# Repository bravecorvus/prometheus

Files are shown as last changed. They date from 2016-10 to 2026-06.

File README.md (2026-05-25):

# Prometheus Smart Clock

### By Andrew Lee

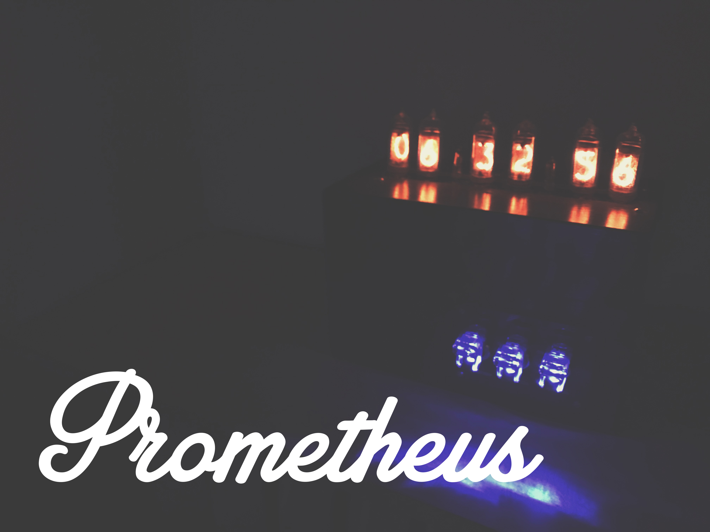
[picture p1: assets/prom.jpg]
Prometheus Clock Cover


Prometheus is the clock that does everything. The 3 main things I want to integrate in this project are:

1. Connect the clock to a bed shaker so my alarm clock can wake me up discretely without waking up my roommate, but also retain the ability to wake me up in a super noisy fashion by playing an alarm tone through my speaker system for when I really need to wake up.
2. A way to set the alarm via my phone, iPad, or Browser through a polished and intuitive web based interface as well as an easy way to set a new alarm sound.
3. Display time using nixie tube displays.

The current golang program accomplishes all 3 of these things marvelously. Check out the [Wiki](https://github.com/gilgameshskytrooper/prometheus/wiki) for specific details on how to implement Prometheus.

### Project Hierarchy

| Directory | Description |
| --- | --- |
| [backend/](backend/) | Go HTTP server, alarm cron loops, bbolt store, GPIO + serial drivers |
| [frontend/](frontend/) | React + Vite + Tailwind + shadcn UI |
| [assets/](assets/) | Project documentation images (READMEs, schematics) |
| [archive/](archive/) | Original Python3/Node prototype (deprecated, kept for reference) |
| [NCS314/](NCS314/) | Vendor docs for the Nixie clock shield |
| [prometheus.service](prometheus.service) | systemd unit; assumes deploy layout under `/home/pi/prometheus/` |

## Build modes

Prometheus has two build modes selected with Go build tags:

- **Production** (default) — full hardware: GPIO bed-shaker control, USB-serial Nixie tube display, `cvlc` audio playback, IP-change email notifications.
- **Demo** (`-tags demo`) — for hosting a public-facing UI showcase. All GPIO and serial code paths are bypassed at compile time; alarm triggers broadcast WebSocket events instead, and the frontend renders a toast (e.g. "Vibration started") to emulate hardware. No `cvlc` or `/dev/gpiomem` required.

`backend/config/config.go` and `config_demo.go` define `config.DemoMode` as a compile-time constant, so unused branches are dead-code-eliminated.

### Build the backend

```bash
cd backend

# Production binary for the Pi (arm64)
GOOS=linux GOARCH=arm64 go build -o ../prometheus .

# Demo binary for arm64
GOOS=linux GOARCH=arm64 go build -tags demo -o ../prometheus-demo .

# Native (macOS / dev)
go build -o ../prometheus .
```

### Build the frontend

```bash
cd frontend
pnpm install
pnpm build       # outputs ./dist
```

### Local development

Run the backend on :3000 and the Vite dev server on :5173 (Vite proxies `/api`, `/audio`, and `/ws` over to the backend):

```bash
# terminal A — backend (dev demo mode is convenient on a laptop)
cd backend && go run -tags demo .

# terminal B — frontend with hot reload
cd frontend && pnpm dev
```

Then open http://localhost:5173.

### Deploy to a Raspberry Pi

The Pi mirrors the repo layout. After a `git clone` of the repo into `/home/pi/prometheus/`, the source-controlled files (service unit, email helper binary, etc.) are already in place; deploying an update just means scp'ing the two build artifacts on top of the clone:

```
/home/pi/prometheus/
├── backend/
│   ├── prometheus              # the cross-compiled Go binary  (scp'd)
│   └── email/prometheusemail   # email helper (already in git)
├── frontend/
│   └── dist/                   # built UI                       (scp'd)
├── data/                       # bbolt DB + uploaded audio (created at first run)
└── prometheus.service          # systemd unit (already in git)
```

From your dev machine:

```bash
# build both artifacts
(cd backend  && GOOS=linux GOARCH=arm64 go build -o ../prometheus .)
(cd frontend && pnpm install && pnpm build)

# scp them into the repo layout on the Pi
scp prometheus       pi@prometheus.local:/home/pi/prometheus/backend/prometheus
scp -r frontend/dist pi@prometheus.local:/home/pi/prometheus/frontend/
```

First-time install on the Pi:

```bash
sudo cp /home/pi/prometheus/prometheus.service /etc/systemd/system/
sudo systemctl daemon-reload
sudo systemctl enable --now prometheus
journalctl -u prometheus -f
```

Subsequent updates:

```bash
sudo systemctl restart prometheus
```

## Implementation
> *To get started quickly, check out the [hardware guide](https://github.com/gilgameshskytrooper/prometheus/wiki/Hardware) and the [software installation guide](https://github.com/gilgameshskytrooper/prometheus/wiki/Software) at the project wiki.*

### Inspiration
hberg32 has already successfully implemented some of the code as well as the hard wiring for a similar project of his. His original code as well as his original schematic is contained in the [hberg32](hberg32/) directory of this repo. His project can be found at: [Merciless Pi Alarm Clock](https://hackaday.io/project/4922-merciless-pi-alarm-clock).

### Hardware

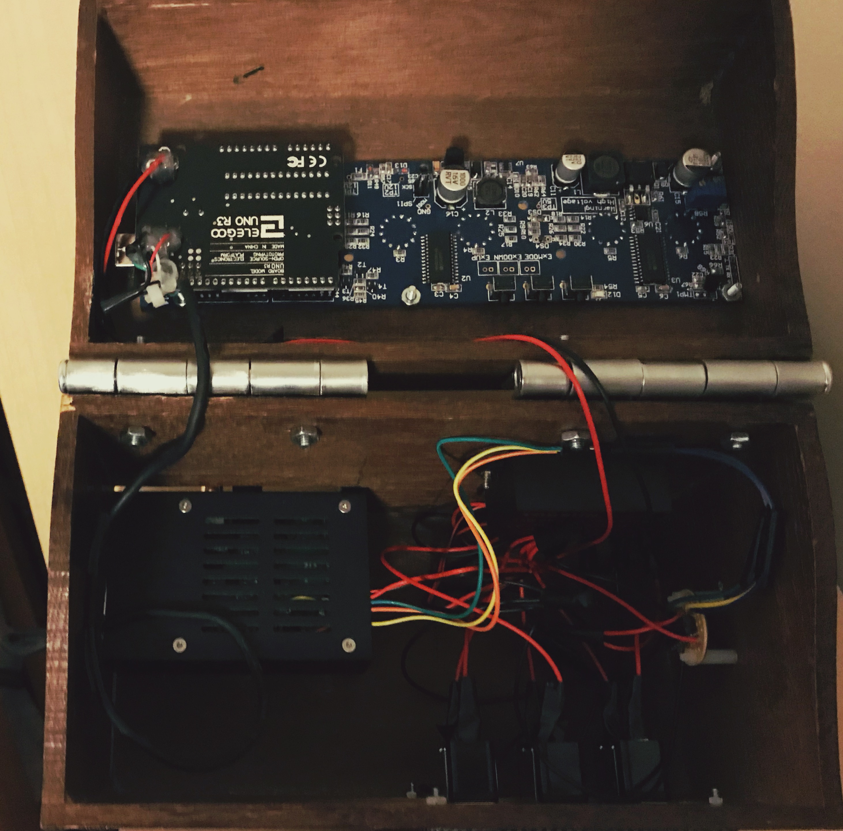
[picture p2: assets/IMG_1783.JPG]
Custom Wire


The hardware in this project is heavily based on hberg32's schematics, which can be found at [Merciless Pi Alarm Schematic](hberg32/PiAlarm.fzz). The schematics of my project can be found at [Prometheus Clock Schematic](/assets/AtomicClockSchematic.fzz).

A few notes on my set-up. My Raspberry Pi has a separate (standard 5V) power source separate from the rest of the Prometheus Clock. The rest of my Project is powered by a 12V @ 2000mA DC Power source, which powers both the Nixie Clock and the Bed Shaker.

As of now, the DC power goes though the breadoard, and goes to both the Nixie Clock, (via a custom barrel plug to breadboard wire I made) as well as a L293D which draws a consistant amount from the main circuit to ensure the clock receives enough V's and the Bed Shaker doesn't fry from too much.

You can read more [here](https://github.com/gilgameshskytrooper/Prometheus/wiki/Hardware-Set-Up)

### Remote Control Alarm Program

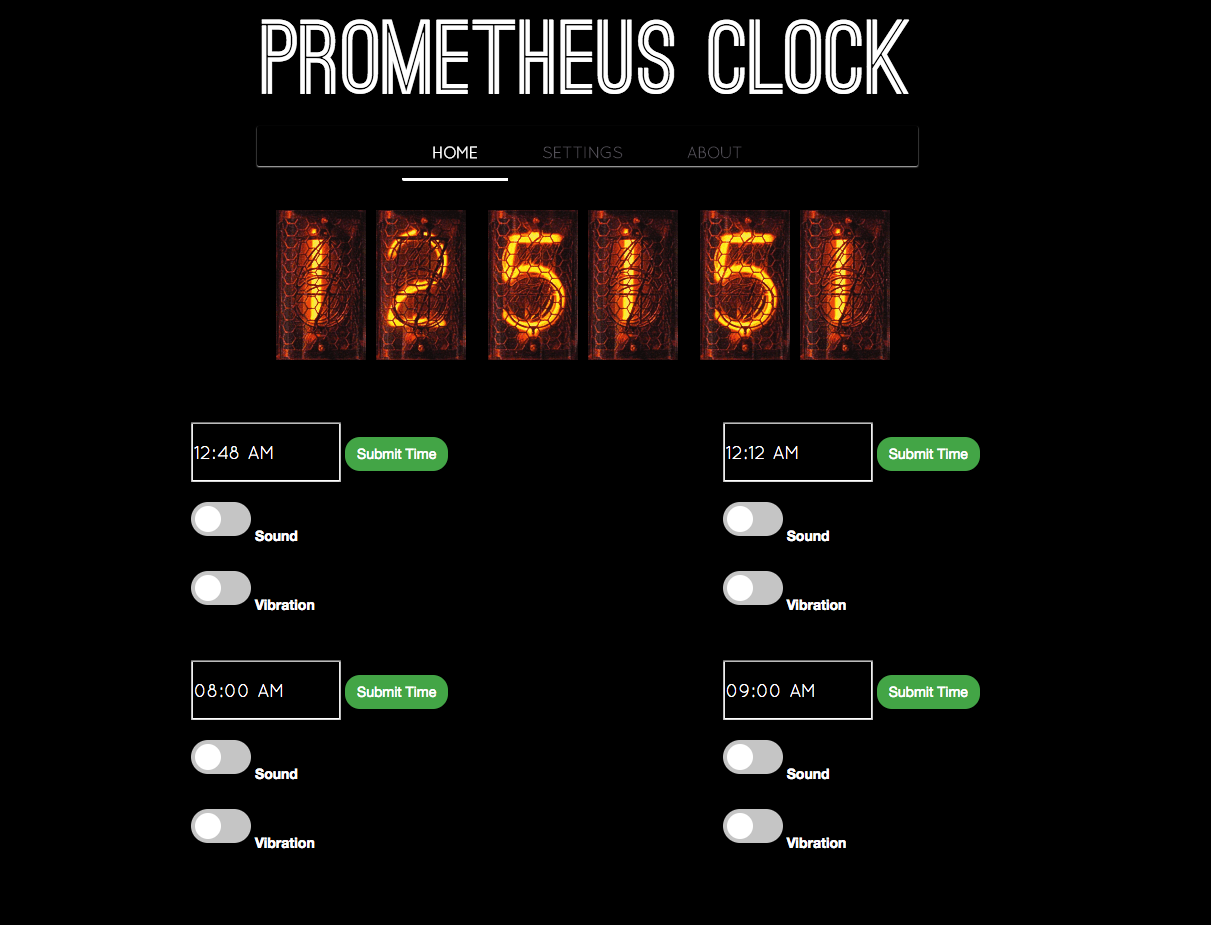
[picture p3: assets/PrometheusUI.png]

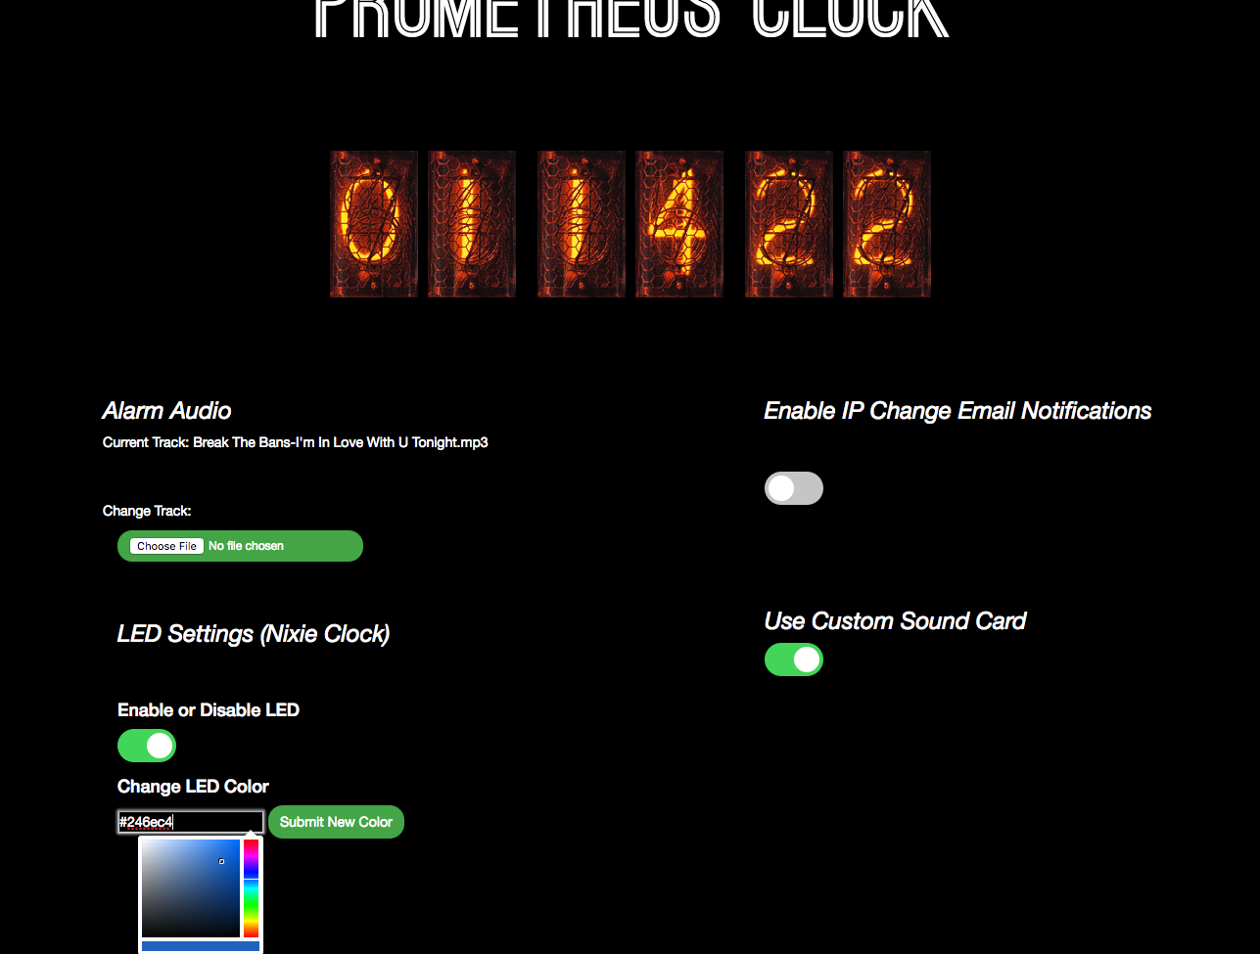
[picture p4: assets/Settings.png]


The UI portion of this project consists of a Golang web server running on the Raspberry Pi which can be accessed on any internet capable browser. The web server serves up the intial [index.html](public/index.html) page at the site root (e.g. 111.111.111:3000 where 111.111.111 is the wlan0 IP of the Raspberry Pi). Through heavy use of [Vue.js](http://vuejs.org/), this page acts as a SPA (single page application). It makes heavy use of the AJAX post requests for the switch buttons, file uploads, and time form submit. It populates the values of the alarm times, sound, and vibration buttons with the values stored in [alarms.json](public/json/alarms.json) which holds the configuration data for the 4 alarms. When the user submits the form, the Golang web server handles the request as a put request, reads the data, changes the internally stored values for the 4 alarms, and writes back the values into [alarms.json](public/json/alarms.json). The only button on the page that requires a hard refresh is the snooze button at the top because the web server needs to compute the value of +10 minutes on the currenly running alarm.

A working demo of the web interface can be found here: [Web Interface Showcase](https://prometheus.gilgameshskytrooper.io)

When the requested the [root](https://prometheus.gilgameshskytrooper.io), it will expose the [public](public/) folder containing an [index.html](https://prometheus.gilgameshskytrooper.io/index.html) file (which browsers automatically load), it loads configurations from the alarm configuration json files: [alarm1.json](https://prometheus.gilgameshskytrooper.io/json/alarm1.json), [alarm2.json](https://prometheus.gilgameshskytrooper.io/json/alarm2.json), [alarm3.json](https://prometheus.gilgameshskytrooper.io/json/alarm3.json), and [alarm4.json](https://prometheus.gilgameshskytrooper.io/json/alarm4.json) It also loads other configuration details like [the name of the sound file](https://prometheus.gilgameshskytrooper.io/json/trackinfo), [LED enable/disable setting](https://prometheus.gilgameshskytrooper.io/json/enableled), [LED color setting](https://prometheus.gilgameshskytrooper.io/json/colors), [IP change email notification enable/disable setting](https://prometheus.gilgameshskytrooper.io/json/enableemail), [IP change email address destination setting](https://prometheus.gilgameshskytrooper.io/json/email), and the [enable/disable custom sound card setting](https://prometheus.gilgameshskytrooper.io/json/customsoundcard).

Vue.js is used to obtain and parse these values from the client side browser when the page is loaded (and incorporated into the Vue instance's data to to populate the page). Other features of Vue such as two way data binding is used inconjunction with AJAX asynchronous POST to ensure the page doesn't have to reload unless necessary.

### [Main Alarm Logic](./main.go)
Using a 3rd party library, Golang is also able to control the hardware interfaces (bed vibrator and speakers). The main logic for when to start running an alarm is a cron task that runs once a minute: if an alarm time configuration matches the current time, then run the relevant waking methods (i.e. vibration/sound). Furthermore, it functions as a web server that serves the front-end UI described above so that users can access the alarm controls from any web capable device.

More specific implementation information is written [here](Prometheus.md).

## [Where's My WiFi?](SetUpEduroamOnPi.md)
Because my school happens to disable ssh and VNC connections for users on the guest network (presumably for security reasons), I needed to set up my Raspberry Pi to work nicely with the school's eduroam. However, getting this to work was quite the struggle, and it seems to be a common issue for aspiring inventors trying to get their Raspberry Pi to work on their school's implementation of eduroam. Therefore, I carefully documented the steps I took to connect my Pi to the encrypted network. For anyone having trouble connecting their Pi (or any single-board computers such as chip) to eduroam, I encourage you to take a look at this document.

[Setting Up RPi to work with Eduroam](SetUpEduroamOnPi.md)

## Contact
Feel free to contact me at [me@gilgameshskytrooper.io](mailto:me@gilgameshskytrooper.io) if you have any suggestions, or want to contribute to this project.

## Special Thanks
[hberg32](https://hackaday.io/hberg32) was super helpful in helping this project become what it is today. I would not even know where to start to build such an alarm clock without his guidance.

Also, AFCH from [GRA & AFCH](https://github.com/afch) who produces the nixie clock kit I bought was also monumental in helping me modify his Arduino Sketch and to add serial USB communication functionality between the Pi and the Clock.

The default sound included in the [public/assets](public/assets) folder is the song [I'm in Love With U Tonight](http://freemusicarchive.org/music/Break_The_Bans/Youth/05_Im_in_love_with_you_tonight) which is released under the Creative Commons license. I would like to thank Kukkovka Hell Studios and Alex Fry, Vadim Bogorodksi, Andrew Bones, and Yaroslav Tregubov for their work.

I am utilizing the  [Quicksand](http://www.typophile.com/node/50437) and [Ostrich Sans](https://www.fontsquirrel.com/fonts/ostrich-sans) fonts for this project. I would like to thank [Andrew Paglinawan](https://www.fontsquirrel.com/fonts/list/foundry/andrew-paglinawan) and [Tyler Finck](https://www.fontsquirrel.com/fonts/list/foundry/tyler-finck) for their beautiful work.

Furthermore, I would like to thank Čestmír Hýbl for his work in creating the [JavaScript based Nixie Clock](http://cestmir.freeside.sk/projects/dhtml-nixie-display/) used in the front-end of this project.

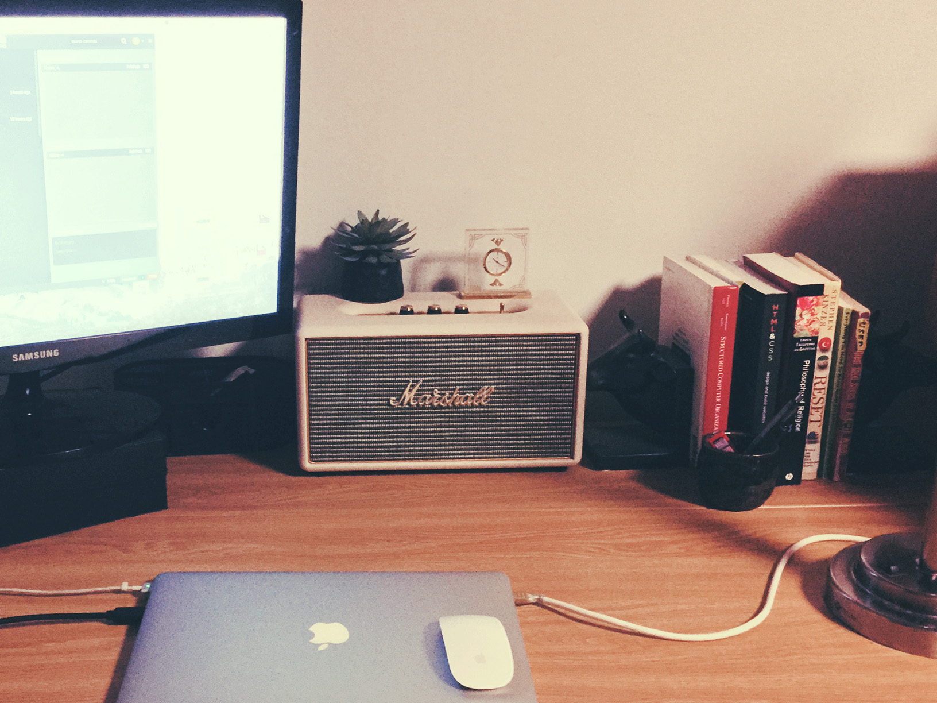
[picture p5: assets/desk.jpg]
Desk


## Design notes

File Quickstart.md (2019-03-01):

# I Just Want to Get This Up and Running

If this is you, then this section will describe the minimum number of steps to get this up and running (I suggest against this since my setup is pretty specific to my needs. The program has been tested extensively on Raspberry Pi 3B, but it might work on other Pi, or Pi-alike devices (either as is, or potentially with some modifications).

## Software Stuff

1. Install the executable binary from Github

```
wget https://github.com/gilgameshskytrooper/prometheus/releases/download/v2.2.3/prometheus.v2.2.3.zip
unzip prometheus.v2.2.3.zip
rm prometheus.v2.2.3.zip
```

2. Install software dependency

```
$sudo apt install vlc-nox
```

3. If you want the program to run on boot, add the executable command in `rc.local`

```
$vi rc.local
```

```
[PATH_TO_PROMETHEUS]/prometheus &
```

4. Then, you need to make sure root can execute cvlc (since VLC disables root by default)
```
sudo apt install bless
sudo bless $(which cvlc)
sed -i 's/geteuid/getppid/' $(which cvlc)
```

If you want a more manual solution, I would suggest running the program in a tmux window (so that the program persists even when you exit ssh) or opening a VNC session and running it in a terminal in the GUI. (If you run the program in regular terminal, it will close the program when you close the ssh connection)

## Hardware Stuff
This part is specific to the hardware you will connect, but here I will share the setup assuming you are using the same setup as me. (e.g. you already own a bed vibrator that runs 12V @ 0.5A and center pin positive, you have a separate power source that is 12V @1+A, and a sound system)

You will need the following Items
| ITEMS | DESCRIPTION | QUANTITY|
|---|---|---|
| Raspberry Pi| Runs all the logic and supplies 5V to the motor driver | x1 |
| L293D | Motor Driver that is will either allow the circuit to the vibrator, or disallow | x1 (I would bulk buy more) |
| Breadboard | Prototyping and connecting everything | x1 |
| Wires | Breadboard wires. Make sure they can withstand some amount of current, if you don't have a Pi breadboard ribbon, get female to male in addition to male to male| x10 |
| USB Audio Interface | Default Pi audio out is not good, so this provides a way to get clean audio | x1 |
| SonicAlert SS12V Bed Shaker | Bed shaker, runs 12V @ 0.5A (peak 12V @ 1.0A) Center Pin Positive | x1 |
| 12V @ 1+A DC Power Supply | The main point here is that it is DC, and that it can supply 12V @ 1A or greater than 1A | x1 |

Connect a circuit using the schematic I uploaded under /root/assets/AtomicClockSchematic.fzz as a model.

If you are having trouble creating the circuit, maybe the following notes I have on how the L293D is layed out can help.

The schematic for the L293D is as follows:

```
Enable 1, 2 Driver Channels      [1   u   16]  Chip Power (5V)
                  Driver Input 1 [2       15] Driver Input 4
                 Driver Output 1 [3       14] Driver Output 4
                        Ground 1 [4       13] Ground 4
                        Ground 2 [5       12] Ground 3
                 Driver Output 2 [6       11] Driver Output 3
                  Driver Input 2 [7       10] Driver Input 3
               Motor Power (12V) [8        9] Enable 3, 4 Driver Channels
```
**The "u" in the center top signifies the divit you see on the chip to differentiate top from bottom**
source: [TexasInstruments](http://www.ti.com/lit/ds/symlink/l293.pdf)

Where the u at the top center represents the divet in the chip to show which side is up. We only need to use one side of the chip.
This chip was initially created to be able to run two stepper motors (stepper meaning bidirectional), one on the left and one on the right.

In this conventional set-up, (as most tutorials online and on Youtube are doing), the left motor will connect to Output 1 (3) and Output 2 (6) while the right motor will connect to Output 3 (11) and output 4 (14). Both motors are powered by the V+ going in from (8) and the chip itself is powered by 16. The next part was hard to understand for me, so bear with me, but Let's say you want to run the left motor "forward" e.g. V+ goes out from Output 1 and the ground (-) goes from the motor to Output 2, then through Ground 1/2 Then you would set 

```
Input 1 = True | Input 2 = False | then Enable 1, 2 = True
```

(Without the Enable 1, 2 = True, nothing would happen). Then the positive 12V would go from 8 to 3 to the motor, then the ground would be motor to 6, to 5 then grounded. To reverse direction of the same motor, you would send

```
Input 1 = False | Input 2 = True | then Enable 1, 2 = True.
```

However, since we are not running a stepper motor, and we only want "center pin positive" current to be flowing, we will only use the first inputs: 

```
Input 1 = True | Input 2 = False | then Enable 1, 2 = True.
```

The main program was programmed with the these 3 GPIO logical pins in mind:

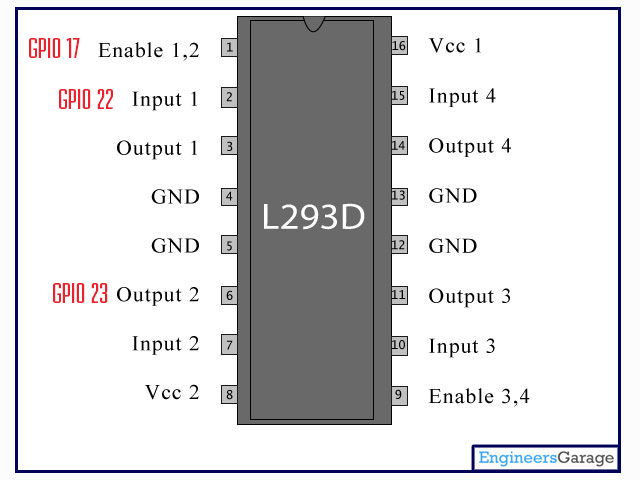
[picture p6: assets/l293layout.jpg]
schematic

If you want to use different pins, you will have to [build from source](Prometheus.md#build-from-source) after you change the used pins in [utils.go](utils/utils.go)

### Sound

To get good sound, you will need to output the sound through a external sound card. The built-in TRS connector are terrible in sound. However, if this is sufficient for your needs, you can skip this section.
**Note, USB sound is OKAY, but since Raspberry USB and LAN share the same lane, this might be a bottleneck if you plan to stream music (like I am doing using [shairport-sync](https://github.com/mikebrady/shairport-sync))**

You need to set up `~/.asoundrc` to read your card.

For USB, it might look like the following.

```
vi ~/.asoundrc

pcm.!default {
    type hw
    card 1
}

ctl.!default {
    type hw
    card 1
}
```

For a custom sound card, it might look like the following:

```
pcm.!default {
	type hw card 0
}
ctl.!default {
	type hw card 0
}
```

Note, if you opt to use a custom card, just change the setting in the bottom right hand corner of the front-end user interface. (If you are not using the exact set-up I'm using, then you will probably have to [build from source](Prometheus.md#build-from-source) after you go into the [main.go](https://github.com/gilgameshskytrooper/prometheus/blob/master/main.go) program and change the `cvlc` commands by hand with the relevant flags to execute and then.

### Access The Alarm Clock

The web interface is accessible at port 3000 (e.g. 111.111.111:3000).

I suggest you use a dynamic DNS provider such as [ddns.net](ddns.net) which lets you access the Pi at a convenient url. You install a program which constantly updates the DDNS provider so that you will still be able to connect to your Pi even when your IP changes. the

However, if you want to use explicit IP's, you can find that out by doing:

```
ifconfig
```

Copy down the address that is listed as wlan0 inet addr. This address is how you will use another device on the same WiFi network to access the website. (i.e. http:111.11.111.111:3000 where you will change 111.11.111.111 to be your IP but keep :3000 at the end to specify you will access the Pi via your web browser at port 3000)

Now, as long as you are same network (Or, if you are lucky enough to get your Pi a static IP, then you will be able to access it from anywhere you have network access), you can access the Web Interface through the site 111.11.111.111:3000 (replacing 111.11.111.111 with the value of IP).

A built in part of the Prometheus program sends you an email whenever the IP of the Pi changes. You can turn off this feature in the front end interface, or change the email address you want to receive email on.

## Have Fun!

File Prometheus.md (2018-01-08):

# Golang Prometheus Software

Golang

### Author: Andrew Lee

If you want documentation, check out the [godocs](https://godoc.org/github.com/gilgameshskytrooper/prometheus) for the project.

## Functionality

- [prometheus](https://godoc.org/github.com/gilgameshskytrooper/prometheus/prometheus) functions as both the server, which hosts the web-based user interface as well as the hardware controlling mechanisms
- [utils](https://godoc.org/github.com/gilgameshskytrooper/prometheus/utils) is the package that contains all the utility functions used by Prometheus
- [gpio](https://godoc.org/github.com/gilgameshskytrooper/prometheus/gpio) contains the specific functions used to execute GPIO.
- [structs](https://godoc.org/github.com/gilgameshskytrooper/prometheus/structs) contains the structs used by Prometheus to store alarms and to unmarshal JSON files
- [nixie](https://godoc.org/github.com/gilgameshskytrooper/prometheus/nixie) contains the code used to interact with the [Arduino nixie clock](https://gra-afch.com/product-category/shield-nixie-clock-for-arduino/). Specifically, the code implemented in [prometheus main package](https://github.com/gilgameshskytrooper/prometheus/blob/master/prometheus.go) sends the current time (using the Go time library) to the Arduino via serial USB.
- [public](public/) contains all the static assets such as index.html, css, and javascript. The front-end functionality heavily utilizes [Vue.js](https://vuejs.org/) and I highly recommend it to anyone who is interested in a front-end framework.

## Software Installation
Please refer to the [wiki](https://github.com/gilgameshskytrooper/prometheus/wiki/Software).

## Hardware Set-Up
Please refer to the [wiki](https://github.com/gilgameshskytrooper/prometheus/wiki/Hardware).

## User Interface
See general [user interface page](https://github.com/gilgameshskytrooper/Prometheus/wiki/User-Interface-Tutorial)

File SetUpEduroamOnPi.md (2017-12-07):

# Setting Up Raspberry Pi to work on Eduroam

### By Andrew Lee

## Introduction
This is a guide I put together in order to get my Raspberry Pi to work on my school's eduroam network.

Just to make things easier,
 ```
sudo su
 ```
(most of these commands will need root permissions)

The default cat_installer shell script file did not install the correct profiles and I needed to execute this file, use the outputs, and manually configure the configuration files. I am compiling this information for anyone who is having trouble connecting a single-board computer to the St. Olaf Eduroam Network specifically, or your eduroam network.

## First Cycle of Installation (Causing a failed script execution to generate the necessary configuration files)

Basically, this is splitting the process into two parts. 1st, we will purposefully cause a failed eduroam installation in order to generate the necessary .pem key file and the correct wpa_supplicant.

### Download The Shell Script
Download the shell commands from this link (or your equivalent cat_installer.sh scripts provided by your school): 
https://www.stolaf.edu/files/it/eduroam/eduroam-linux-SOC.sh

Go into that folder, and give the file execution permissions

```
chmod 777 eduroam-linux-SOC.sh
```

### Execute the Script (This will fail, but do not worry)

Execute the script.
The script will now execute. Enter your St. Olaf Login details (with full credintials [e.g. username@stolaf.edu])
The script will tell you it failed but do not worry, this was our aim.
Make sure you click yes on the options asking if you want the script to generate the wpa_supplicant file in plaintext format. (We will need this later)

### Backup the Generated Config Files

Now the failed runthrough of the script generated the wpa_supplicant profile that we will need later.

```
cd /root/.cat_installer/
```

You will see 2 files in there: ca.pem and cat_installer.conf. Copy these files into a directory of your choice that you will remember later. Basically, even the next step of successfully installing the eduroam profile will not allow you to connect to the internet since the script fails to change some key configuration files.

Create a new directory in root called .cat_installer, and copy the ca.pem key file in there.

```
cd /root
mkdir .cat_installer
cp /path-to-ca.pem /root/.cat_installer/ca.pem
```

Next, we will do the successful installation of the network profile for eduroam

## Second Installation Cycle (Successful)

### Installing the Necessary Software Components to Get a Successful Installation of Eduroam Profiles

Before doing anything, install the following utilities in your linux distribution (it will be used in the Shell ):

```
apt-get install dbus
apt-get install re
apt-get install uuid
apt-get install network-manager
```

### Modify NetworkManager.conf So it is the Default Controller for Wifi

```
nano /etc/NetworkManager/NetworkManager.conf

[main]
plugins=ifupdown.keyfile

[ifupdown]
managed=true
```

Where is sas "managed=false", replace with "managed=true"

### Execute the CAT_INSTALLER Shell Script Again (This Time, it Will Run Successfully)

Now go back and run eduroam-linux-SOC.sh
This time around, everything will execute correctly without a problem.

## Entering In The Correct Values in the wpa_supplicant.conf file

Now open cat_installer.conf (that you backed up as the last step of the failed configuration step) in a text editor

open /etc/wpa_supplicant/wpa_supplicant.conf in an editor of your choice.

```
nano /etc/wpa_supplicant/wpa_supplicant.conf
```

Leaving the top part as is

```
ctrl_interface=DIR=/var/run/wpa_supplicant GROUP=netdev
update_config=1
country=US
```

remove the rest of the various network configurations

copy and paste the information stored in cat_installer.conf into the wpa_supplicant.confhow t

Your final code should look something like this:

```
ctrl_interface=DIR=/var/run/wpa_supplicant GROUP=netdev
update_config=1
country=US

network={
        ssid="eduroam"
        key_mgmt=WPA-EAP
        pairwise=CCMP
        group=CCMP TKIP
        eap=PEAP
        identity="username@stolaf.edu"
        password="PassWord"
        ca_cert="/root/.cat_installer/ca.pem"
        domain_suffix_match="ad.stolaf.edu"
        phase2="auth=MSCHAPV2"
}
```

And save the information.

## Editing /etc/network/interfaces To Force NetworkManager to use the wpa_supplicant.conf As the Default Settings to Connect

Next, open /etc/network/interfaces on your favorite code editor.

```
nano /etc/network/interfaces
```

Now this part is necessary because we will be telling the current network handler NetworkManager, to get all the configuration information from the wpa_supplicant.config file we just patched to work for eduroam.

By default, there is alot of stuff enabled.
Now go through and comment out every line of the text by putting a "#" in front of each line. (we will comment out rather than delete just in case we need to reset everything)

At the bottom, paste the following code:

```
auto wlan0
allow-hotplug wlan0
iface wlan0 inet dhcp
        wpa-ssid eduroam
        pre-up wpa_supplicant -B -Dwext -i wlan0 -c/etc/w$
        post-down killall -q wpa_supplicant
```

## Restart Machine

Finally, restart the machine. At this point, you should see your machine as connected to eduroam

If you are still stuck with no luck with connecting to eduroam, here is when the trial and error comes in. Basically, you will be editing 3 files:

```
/etc/network/interfaces
/etc/NetworkManager/NetworkManager.conf
/etc/wpa_supplicant/wpa_supplicant.conf
```

So open them up using your favorite editor, then also have a spare Terminal open on the root user.

Basically, using the picture I have down below, edit the various file settings. (Note: You should always create backup copies of any files before you edit them so you can replace the new one if it really screws up your settings)

Every time you edit a file and save it, you will run the following command
```
systemctl daemon-reload
/etc/init.d/networking restart
```

## Fixing System Time

After you restart there is just one more step. Because the Pi does not come with a built in internal clock, the system date/time values will be so off that you will not be able to connect to the internet. (Which means you can't connect to an NTP server to update your time)

Therefore, manually change your time to the correct time. After this, you should be able to connect to the internet without an issue.

Don't forget to remove the eduroam-linux-SOC.sh. We gave it 777 permissions (out of laziness) so after you get connected, you definitely don't want to leave this file around.

## Here is my current setup for reference
Correct Set Up

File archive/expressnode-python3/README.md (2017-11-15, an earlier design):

# Node.js Web Server for Atomic Pi Project
## Andrew Lee

***Please note, the Node.js + Python3 program is no longer being actively developed, and is stored on the repo for referencing purposes. Please refer to my newer and better [golang implementation](../golang/)***

### [Main Project](https://github.com/gilgameshskytrooper/Prometheus)

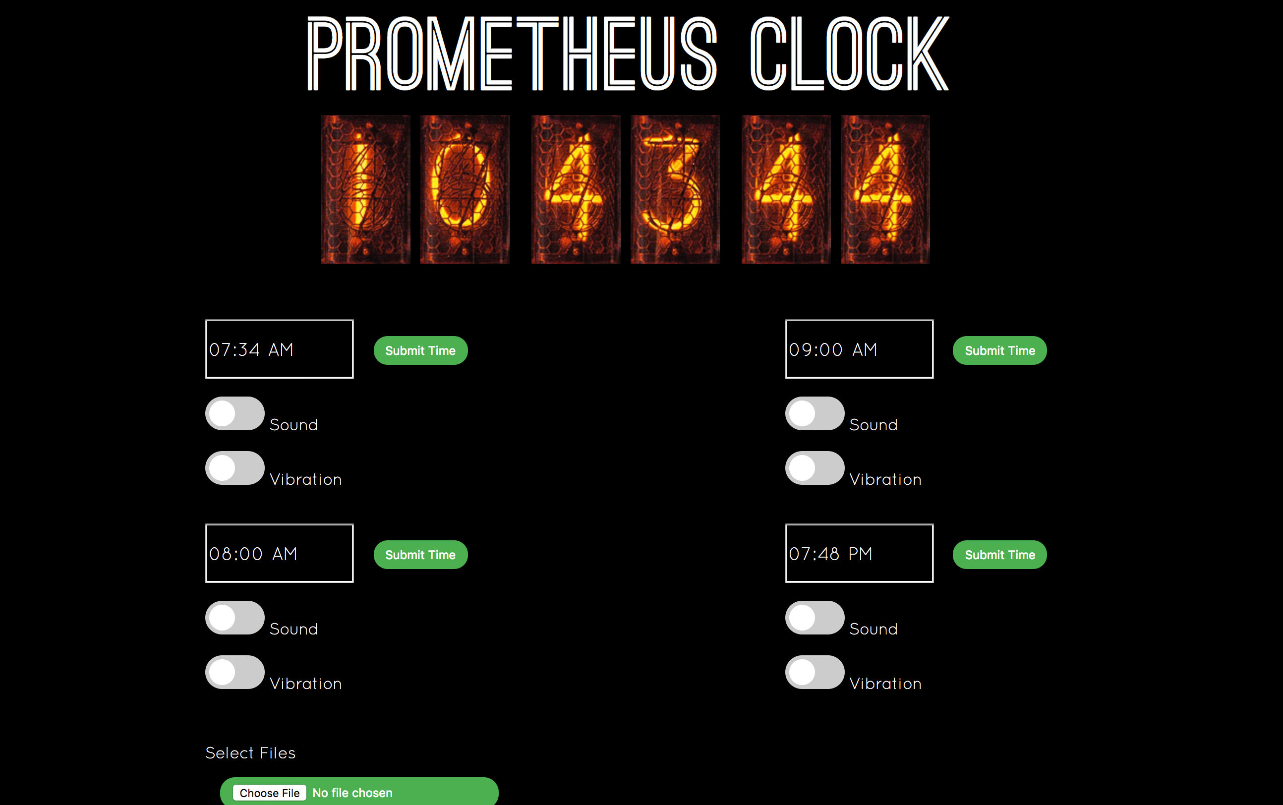
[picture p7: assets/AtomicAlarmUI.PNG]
Atomic Alarm UI


### Credits
I used the following technologies to make this website:
The HTML is loosely based on Gokul S Krishnan's [simple_alarm](https://github.com/gsk1692/simple_alarm).
[jQuery](http://jquery.com/) is a dependency of Bootstrap.
[node.js](https://nodejs.org/en/) provides the RESTful services needed to run the UI.
[npm](https://www.npmjs.com/) is the package manager for node.js I needed to install various tools for the project.

### Role in the Atomic Clock Project
This server runs the web server that controls the Alarm Configuration files. There are 4 of them: [alarm1.json](/public/json/alarm1.json), [alarm2.json](/public/json/alarm2.json), [alarm3.json](/public/json/alarm3.json), and [alarm4.json](/public/json/alarm4.json). The main alarm clock function will use the configuraton files as the basis for when to run an alarm and to decide when an alarm was enabled or disabled.

### Installation
If you haven't cloned the main Atomic Clock Project
```
$sudo apt-get install git
$git clone https://github.com/gilgameshskytrooper/Prometheus.git
```

Next, we want to make sure you have node.js and npm:
```
$sudo apt-get install node npm
```

Next we want to install the node app dependencies for ```express```, ```body-parser```, and ```jsonfile```. Furthermore, we will need another node application called ```forever``` to run the web server as a daemon (basically useful for running this in the background without having to keep a terminal window open)

```
$cd Prometheus/archive/webinterface
$sudo node install
$sudo node install forever -g
```

At this point, we will have everything we will need to run the server.

The most basic way to run the server is

```
$cd /path_to_webinterface_root/
$node server.js
```

However, if you ssh'ed into your Pi, or close the terminal window by mistake, this will close the web server since it will be running as a main process on the terminal window.

Instead, I suggest running the server through ```forever``` which will run the web server in the background, if your ssh connection were to time out, or disconnect, it would still be running.

```
$cd /path_to_webinterface_root/
$sudo forever start server.js
```

If you are not running the server for the first time, you will need to add the ```-a``` tag (for append log file rather than create new) to the forever command or else forever will throw an error due to there being a log file already.

```
$sudo forever start -a server.js
```

To test your server, use any device with a web browser and connect to [111.111.111:3000](111.111.111:3000) (where 111.111.111 is the IP of your Pi. If you don't know this value, go to your Pi and run ```sudo ifconfig```. It will be the value listed as inet addr:). **Make sure you add ":3000" after the address in the browser as this specifies you will be sending the get request to port 3000 of your Pi**

Congratulations, you now have a fully functional Atomic Clock User Interface.

### How it all works
When the requested the root [111.111.111:3000](111.111.111:3000), it will send [index.html](/public/index.html), it loads it from the alarm configuration files: [alarm1.json](/public/json/alarm1.json), [alarm2.json](/public/json/alarm2.json), [alarm3.json](/public/json/alarm3.json), and [alarm4.json](/public/json/alarm4.json).

When the user fills out the form, it will update the configuration files and reload the page. **Note: You cannot send the form from the [index.html link](/public/index.html), you must use the [111.111.111:3000](111.111.111:3000)**

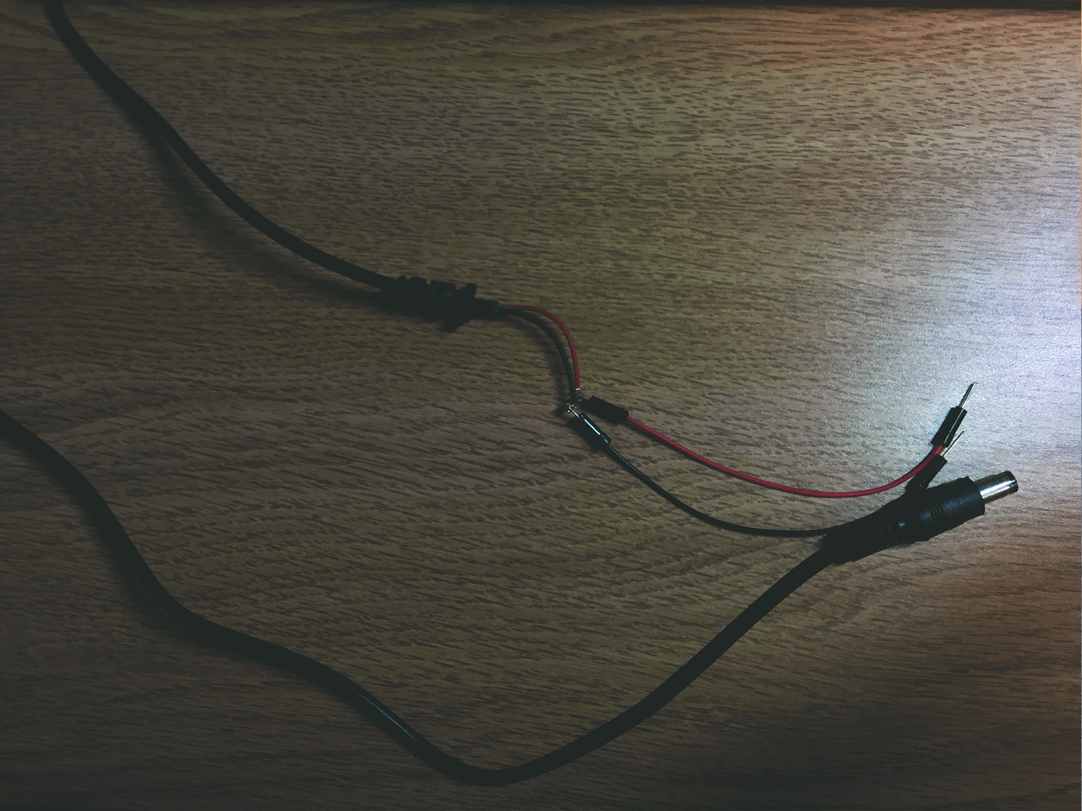
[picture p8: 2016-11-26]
assets/nixie wire.jpg

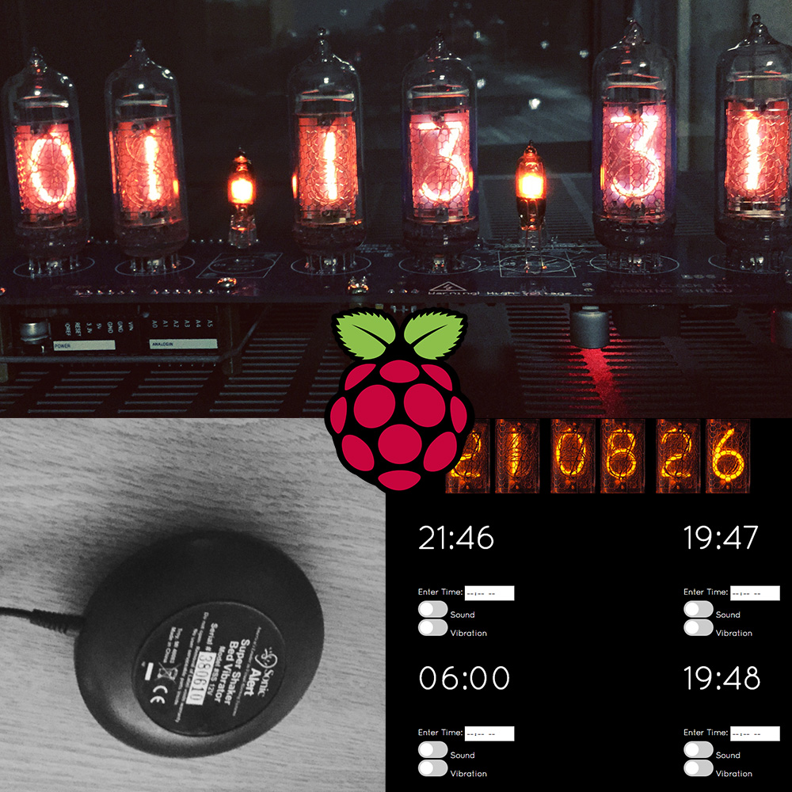
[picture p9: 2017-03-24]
assets/newcover.jpg

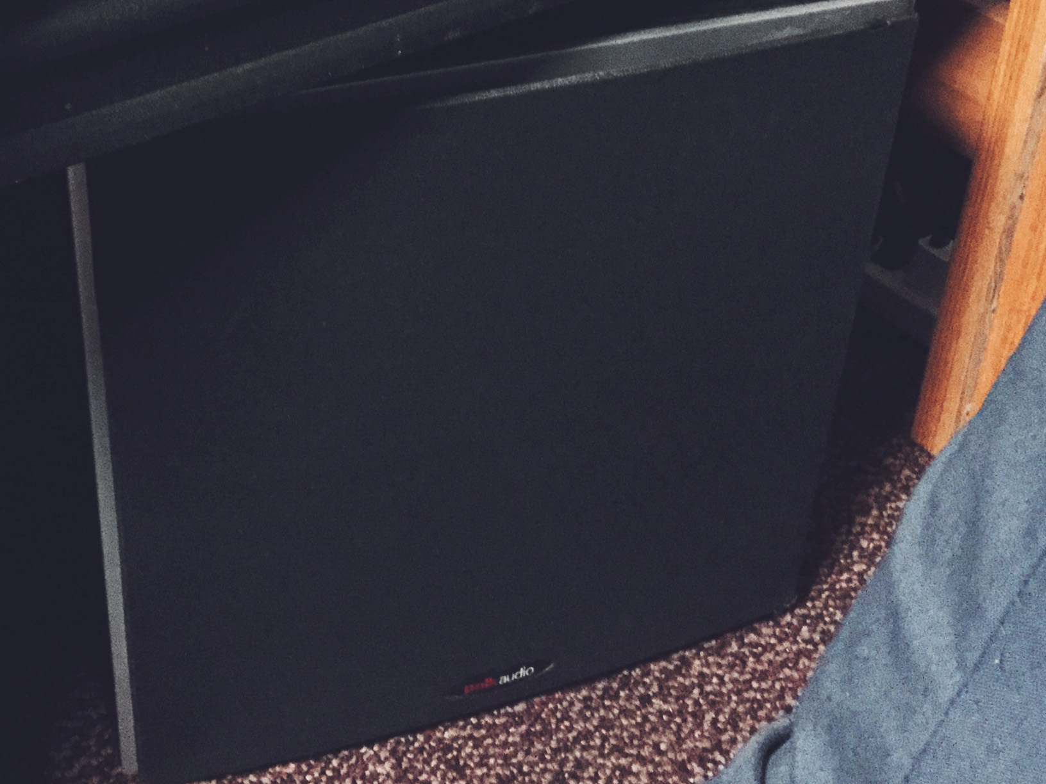
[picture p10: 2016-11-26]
assets/subs.jpg

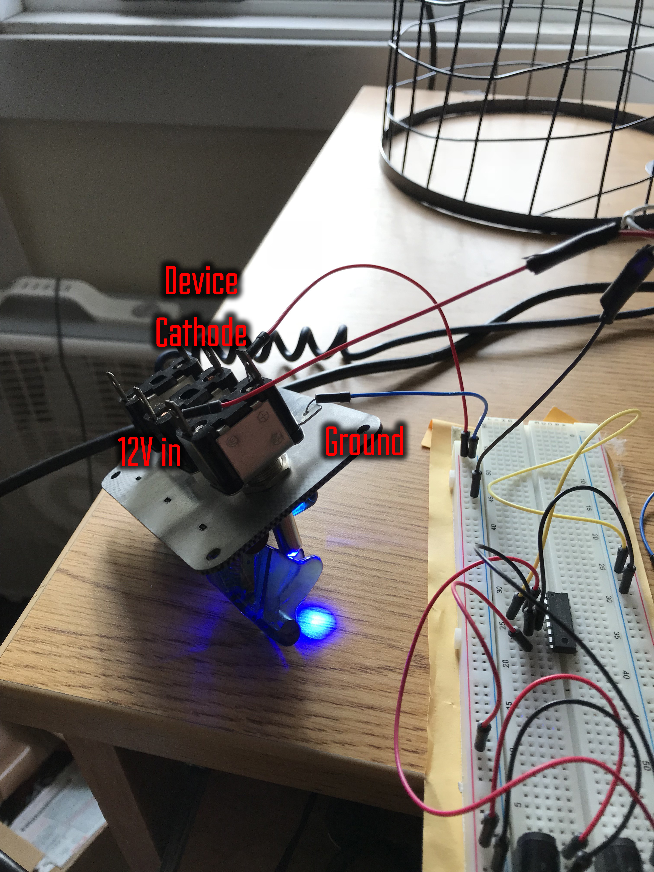
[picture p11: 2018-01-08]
assets/toggle switch.jpg

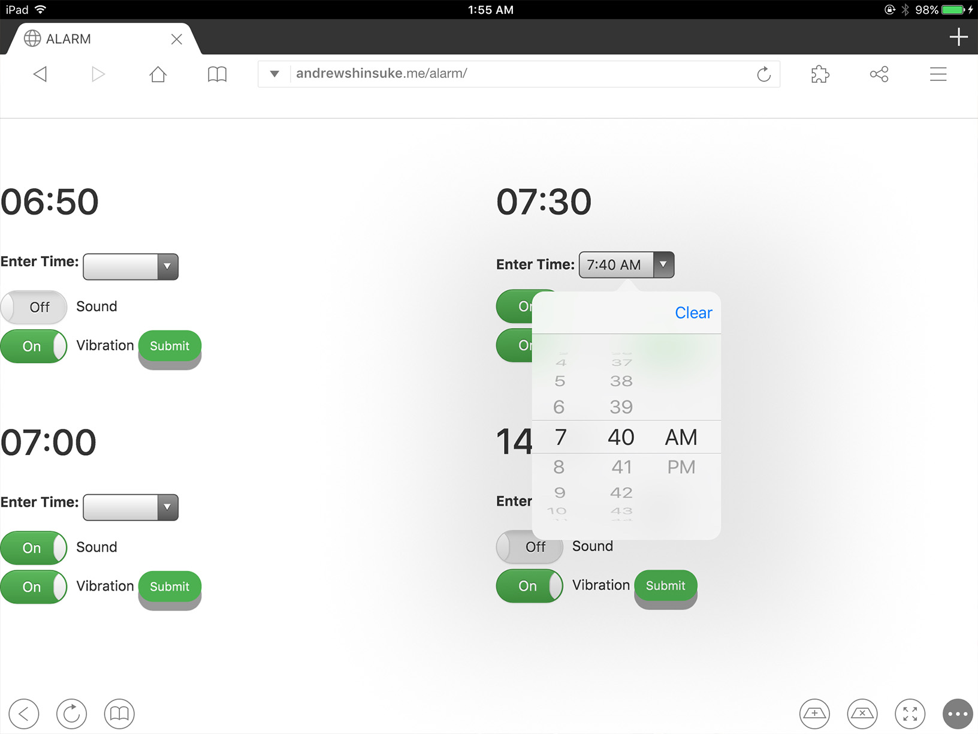
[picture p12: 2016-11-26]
assets/interface.jpg

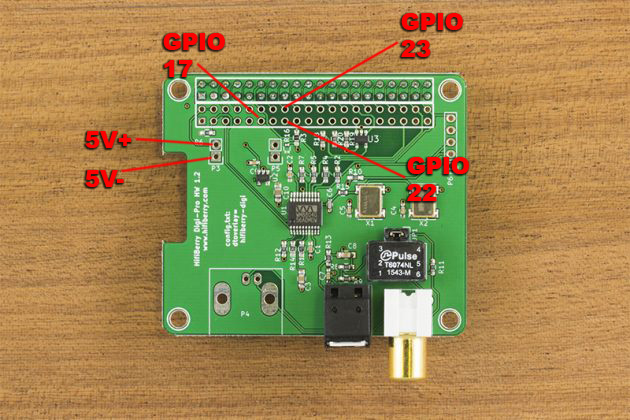
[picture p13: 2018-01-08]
assets/digiplus_pro-630x420.jpg

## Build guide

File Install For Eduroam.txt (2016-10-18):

This is a guide I put together in order to get my Raspberry Pi to work on my school's eduroam network.

Just to make things easier, sudo su (most of these commands will need root permissions)

The default cat_installer shell script file did not install the correct profiles and I needed to execute this file, use the outputs, and manually configure the configuration files. I am compiling this information for anyone who is having trouble connecting a single-board computer to the St. Olaf Eduroam Network specifically, or your eduroam network.

Basically, this is splitting the process into two parts. 1st, we will purposefully cause a failed eduroam installation in order to generate the necessary .pem key file and the correct wpa_supplicant.

Download the shell commands from this link (or your equivalent cat_installer.sh scripts provided by your school): 
https://www.stolaf.edu/files/it/eduroam/eduroam-linux-SOC.sh

Go into that folder, and give the file execution permissions
chmod 777 eduroam-linux-SOC.sh

Execute the script.
The script will now execute. Enter your St. Olaf Login details (with full credintials [e.g. username@stolaf.edu])
The script will tell you it failed but do not worry, this was our aim.
Make sure you click yes on the options asking if you want the script to generate the wpa_supplicant file in plaintext format. (We will need this later)

Now the failed runthrough of the script generated the wpa_supplicant profile that we will need later.

cd /root/.cat_installer/
You will see 2 files in there: ca.pem and cat_installer.conf. Copy these files into a directory of your choice that you will remember later.

Next, we will do the successful installation of the network profile for eduroam

Before doing anything, install the following utilities in your linux distribution (it will be used in the Shell ):
apt-get install dbus
apt-get install re
apt-get install uuid
apt-get install network-manager

Now go back and run eduroam-linux-SOC.sh
This time around, everything will execute correctly without a problem.

Now open cat_installer.conf (that you backed up as the last step of the failed configuration step) in a text editor

open /etc/wpa_supplicant/wpa_supplicant.conf in an editor of your choice
nano /etc/wpa_supplicant/wpa_supplicant.conf

Leaving the top part
ctrl_interface=DIR=/var/run/wpa_supplicant GROUP=netdev
update_config=1
country=US

remove the rest of the various network configurations

copy and paste the information stored in cat_installer.conf into the wpa_supplicant.conf

Your final code should look something like this:
ctrl_interface=DIR=/var/run/wpa_supplicant GROUP=netdev
update_config=1
country=US

network={
        ssid="eduroam"
        key_mgmt=WPA-EAP
        pairwise=CCMP
        group=CCMP TKIP
        eap=PEAP
        identity="username@stolaf.edu"
        password="PassWord"
        ca_cert="/root/.cat_installer/ca.pem"
        domain_suffix_match="ad.stolaf.edu"
        phase2="auth=MSCHAPV2"
}

And save the information.

Next, open /etc/network/interfaces on your favorite code editor.
Now this part is necessary because we will be telling the current network handler NetworkManager, to get all the configuration information from the wpa_supplicant.config file we just patched to work for eduroam.

By default, there is alot of stuff enabled.
Now go through and comment out every line of the text by putting a "#" in front of each line. (we will comment out rather than delete just in case we need to reset everything)

At the bottom, paste the following code:
#CONFIG SETTINGS FROM CAT_INSTALLER
auto wlan0
allow-hotplug wlan0
iface wlan0 inet dhcp
        wpa-ssid eduroam
        pre-up wpa_supplicant -B -Dwext -i wlan0 -c/etc/w$
        post-down killall -q wpa_supplicant

Finally, restart the machine. At this point, you should see your machine as connected to eduroam

After you restart there is just one more step. Because the Pi does not come with a built in internal clock, the system date/time values will be so off that you will not be able to connect to the internet. (Which means you can't connect to an NTP server to update your time)

Therefore, manually change your time to the correct time. After this, you should be able to connect to the internet without an issue.

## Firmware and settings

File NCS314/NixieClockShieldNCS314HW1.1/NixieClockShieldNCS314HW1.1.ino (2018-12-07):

const String FirmwareVersion="010200";
//Format                _X.XX__    
//NIXIE CLOCK SHIELD NCS314 by GRA & AFCH (fominalec@gmail.com)
//1.02 17.10.2016
//Fixed: RGB color controls
//Update to Arduino IDE 1.6.12 (Time.h replaced to TimeLib.h)
//1.01
//Added RGB LEDs lock(by UP and Down Buttons)
//Added Down and Up buttons pause and resume self testing
//25.09.2016 update to HW ver 1.1
//25.05.2016
 
#include <SPI.h>
#include <Wire.h>
#include <ClickButton.h>
#include <TimeLib.h>
#include <Tone.h>
#include <EEPROM.h>

const byte LEpin=7; //pin Latch Enabled data accepted while HI level
const byte DHVpin=5; // off/on MAX1771 Driver  Hight Voltage(DHV) 110-220V 
const byte RedLedPin=9; //MCU WDM output for red LEDs 9-g
const byte GreenLedPin=6; //MCU WDM output for green LEDs 6-b
const byte BlueLedPin=3; //MCU WDM output for blue LEDs 3-r
const byte pinSet=A0;
const byte pinUp=A2;
const byte pinDown=A1;
const byte pinBuzzer=2;
const byte pinUpperDots=12; //HIGH value light a dots
const byte pinLowerDots=8;  //HIGH value light a dots
const word fpsLimit=16666; // 1/60*1.000.000 //limit maximum refresh rate on 60 fps

/* CHANGES */
/* Counter used to figure out if RTC neesd to be updated. If the USB Serial is being used to read the time over and over again, theres no reason to setRTCDateTime() every time. So this is used to do it once every 60 times */
int updateRTCCounter;
/* Boolean to keep track of whether or not the last time updateDisplayString() using USB Serial input, or not */
bool lastUpdatedByNTP;

String Temp = "";
char var;

String stringToDisplay="000000";// Conten of this string will be displayed on tubes (must be 6 chars length)
int menuPosition=0; // 0 - time
                    // 1 - date
                    // 2 - alarm
                    // 3 - 12/24 hours mode
                    
byte blinkMask=B00000000; //bit mask for blinkin digits (1 - blink, 0 - constant light)

//                      0      1      2      3      4      5      6      7      8       9
word SymbolArray[10]={65534, 65533, 65531, 65527, 65519, 65503, 65471, 65407, 65279, 65023};

byte dotPattern=B00000000; //bit mask for separeting dots 
                          //B00000000 - turn off up and down dots 
                          //B1100000 - turn off all dots

#define DS1307_ADDRESS 0x68
byte zero = 0x00; //workaround for issue #527
int RTC_hours, RTC_minutes, RTC_seconds, RTC_day, RTC_month, RTC_year, RTC_day_of_week;

//--    ------------0--------1--------2-------3--------4--------5--------6--------7--------8--------9--------10-------11-------12-------13-------14
//         names:  Time,   Date,   Alarm,   12/24    hours,   mintues, seconds,  day,    month,   year,    hour,   minute,   second alarm01  hour_format 
//                  1        1        1       1        1        1        1        1        1        1        1        1        1        1        1
int parent[15]={    0,       0,       0,      0,       1,       1,       1,       2,       2,       2,       3,       3,       3,       3,       4};
int firstChild[15]={4,       7,       10,     14,      0,       0,       0,       0,       0,       0,       0,       0,       0,       0,       0};
int lastChild[15]={ 6,       9,       13,     14,      0,       0,       0,       0,       0,       0,       0,       0,       0,       0,       0};
int value[15]={     0,       0,       0,      0,       0,       0,       0,       0,       0,       0,       0,       0,       0,       0,      24};
int maxValue[15]={  0,       0,       0,      0,      23,      59,      59,      31,      12,      99,      23,      59,      59,       1,      24};
int minValue[15]={  0,       0,       0,      12,     00,      00,      00,       1,       1,      00,      00,      00,      00,       0,      12};
byte blinkPattern[15]={
                    B00000000, 
                             B00000000, 
                                      B00000000, 
                                              B00000000, 
                                                      B00000011, 
                                                                B00001100, 
                                                                          B00110000, 
                                                                                  B00000011, 
                                                                                           B00001100, 
                                                                                                    B00110000, 
                                                                                                             B00000011, 
                                                                                                                      B00001100, 
                                                                                                                                B00110000,
                                                                                                                                        B11000000,  
                                                                                                                                            B00001100};
#define TimeIndex        0 
#define DateIndex        1 
#define AlarmIndex       2 
#define hModeIndex       3 
#define TimeHoursIndex   4 
#define TimeMintuesIndex 5
#define TimeSecondsIndex 6
#define DateDayIndex     7
#define DateMonthIndex   8
#define DateYearIndex    9 
#define AlarmHourIndex   10
#define AlarmMinuteIndex 11
#define AlarmSecondIndex 12
#define Alarm01          13
#define hModeValueIndex  14

bool editMode=false;

long downTime=0;
long upTime=0;
const long settingDelay=150;
bool BlinkUp=false;
bool BlinkDown=false;
unsigned long enteringEditModeTime=0;
bool RGBLedsOn=true;
byte RGBLEDsEEPROMAddress=0; 
byte HourFormatEEPROMAddress=1;
byte AlarmTimeEEPROMAddress=2;//3,4,5
byte AlarmArmedEEPROMAddress=6;
byte LEDsLockEEPROMAddress=7;   
byte LEDsRedValueEEPROMAddress=8; 
byte LEDsGreenValueEEPROMAddress=9; 
byte LEDsBlueValueEEPROMAddress=10;   

//buttons pins declarations
ClickButton setButton(pinSet, LOW, CLICKBTN_PULLUP);
ClickButton upButton(pinUp, LOW, CLICKBTN_PULLUP);
ClickButton downButton(pinDown, LOW, CLICKBTN_PULLUP);
///////////////////

Tone tone1;
#define isdigit(n) (n >= '0' && n <= '9')
//char *song = "MissionImp:d=16,o=6,b=95:32d,32d#,32d,32d#,32d,32d#,32d,32d#,32d,32d,32d#,32e,32f,32f#,32g,g,8p,g,8p,a#,p,c7,p,g,8p,g,8p,f,p,f#,p,g,8p,g,8p,a#,p,c7,p,g,8p,g,8p,f,p,f#,p,a#,g,2d,32p,a#,g,2c#,32p,a#,g,2c,a#5,8c,2p,32p,a#5,g5,2f#,32p,a#5,g5,2f,32p,a#5,g5,2e,d#,8d";
char *song = "PinkPanther:d=4,o=5,b=160:8d#,8e,2p,8f#,8g,2p,8d#,8e,16p,8f#,8g,16p,8c6,8b,16p,8d#,8e,16p,8b,2a#,2p,16a,16g,16e,16d,2e";
//char *song="VanessaMae:d=4,o=6,b=70:32c7,32b,16c7,32g,32p,32g,32p,32d#,32p,32d#,32p,32c,32p,32c,32p,32c7,32b,16c7,32g#,32p,32g#,32p,32f,32p,16f,32c,32p,32c,32p,32c7,32b,16c7,32g,32p,32g,32p,32d#,32p,32d#,32p,32c,32p,32c,32p,32g,32f,32d#,32d,32c,32d,32d#,32c,32d#,32f,16g,8p,16d7,32c7,32d7,32a#,32d7,32a,32d7,32g,32d7,32d7,32p,32d7,32p,32d7,32p,16d7,32c7,32d7,32a#,32d7,32a,32d7,32g,32d7,32d7,32p,32d7,32p,32d7,32p,32g,32f,32d#,32d,32c,32d,32d#,32c,32d#,32f,16c";
//char *song="DasBoot:d=4,o=5,b=100:d#.4,8d4,8c4,8d4,8d#4,8g4,a#.4,8a4,8g4,8a4,8a#4,8d,2f.,p,f.4,8e4,8d4,8e4,8f4,8a4,c.,8b4,8a4,8b4,8c,8e,2g.,2p";
//char *song="Scatman:d=4,o=5,b=200:8b,16b,32p,8b,16b,32p,8b,2d6,16p,16c#.6,16p.,8d6,16p,16c#6,8b,16p,8f#,2p.,16c#6,8p,16d.6,16p.,16c#6,16b,8p,8f#,2p,32p,2d6,16p,16c#6,8p,16d.6,16p.,16c#6,16a.,16p.,8e,2p.,16c#6,8p,16d.6,16p.,16c#6,16b,8p,8b,16b,32p,8b,16b,32p,8b,2d6,16p,16c#.6,16p.,8d6,16p,16c#6,8b,16p,8f#,2p.,16c#6,8p,16d.6,16p.,16c#6,16b,8p,8f#,2p,32p,2d6,16p,16c#6,8p,16d.6,16p.,16c#6,16a.,16p.,8e,2p.,16c#6,8p,16d.6,16p.,16c#6,16a,8p,8e,2p,32p,16f#.6,16p.,16b.,16p.";
//char *song="Popcorn:d=4,o=5,b=160:8c6,8a#,8c6,8g,8d#,8g,c,8c6,8a#,8c6,8g,8d#,8g,c,8c6,8d6,8d#6,16c6,8d#6,16c6,8d#6,8d6,16a#,8d6,16a#,8d6,8c6,8a#,8g,8a#,c6";
//char *song="WeWishYou:d=4,o=5,b=200:d,g,8g,8a,8g,8f#,e,e,e,a,8a,8b,8a,8g,f#,d,d,b,8b,8c6,8b,8a,g,e,d,e,a,f#,2g,d,g,8g,8a,8g,8f#,e,e,e,a,8a,8b,8a,8g,f#,d,d,b,8b,8c6,8b,8a,g,e,d,e,a,f#,1g,d,g,g,g,2f#,f#,g,f#,e,2d,a,b,8a,8a,8g,8g,d6,d,d,e,a,f#,2g";
#define OCTAVE_OFFSET 0
char *p;

int notes[] = { 0,
NOTE_C4, NOTE_CS4, NOTE_D4, NOTE_DS4, NOTE_E4, NOTE_F4, NOTE_FS4, NOTE_G4, NOTE_GS4, NOTE_A4, NOTE_AS4, NOTE_B4,
NOTE_C5, NOTE_CS5, NOTE_D5, NOTE_DS5, NOTE_E5, NOTE_F5, NOTE_FS5, NOTE_G5, NOTE_GS5, NOTE_A5, NOTE_AS5, NOTE_B5,
NOTE_C6, NOTE_CS6, NOTE_D6, NOTE_DS6, NOTE_E6, NOTE_F6, NOTE_FS6, NOTE_G6, NOTE_GS6, NOTE_A6, NOTE_AS6, NOTE_B6,
NOTE_C7, NOTE_CS7, NOTE_D7, NOTE_DS7, NOTE_E7, NOTE_F7, NOTE_FS7, NOTE_G7, NOTE_GS7, NOTE_A7, NOTE_AS7, NOTE_B7
};

int fireforks[]={0,0,1,//1
                -1,0,0,//2
                 0,1,0,//3
                 0,0,-1,//4
                 1,0,0,//5
                 0,-1,0}; //array with RGB rules (0 - do nothing, -1 - decrese, +1 - increse

void setRTCDateTime(byte h, byte m, byte s, byte d, byte mon, byte y, byte w=1);

int functionDownButton=0;
int functionUpButton=0;
bool LEDsLock=false;

/*******************************************************************************************************
Init Programm
*******************************************************************************************************/
void setup() 
{
  int updateRTCCounter = 0;
  digitalWrite(DHVpin, LOW);    // off MAX1771 Driver  Hight Voltage(DHV) 110-220V
   
  Wire.begin();
  //setRTCDateTime(23,40,00,25,7,15,1);
  
  Serial.begin(115200);
  
    if (EEPROM.read(HourFormatEEPROMAddress)!=12) value[hModeValueIndex]=24; else value[hModeValueIndex]=12;
    if (EEPROM.read(RGBLEDsEEPROMAddress)!=0) RGBLedsOn=true; else RGBLedsOn=false;
    if (EEPROM.read(AlarmTimeEEPROMAddress)==255) {
        value[AlarmHourIndex]=0;
    } else {
        value[AlarmHourIndex]=EEPROM.read(AlarmTimeEEPROMAddress);
    } 
    if (EEPROM.read(AlarmTimeEEPROMAddress+1)==255) {
        value[AlarmMinuteIndex]=0;
    } else {
        value[AlarmMinuteIndex]=EEPROM.read(AlarmTimeEEPROMAddress+1);
    } 
    if (EEPROM.read(AlarmTimeEEPROMAddress+2)==255) value[AlarmSecondIndex]=0; else value[AlarmSecondIndex]=EEPROM.read(AlarmTimeEEPROMAddress+2);
    if (EEPROM.read(AlarmArmedEEPROMAddress)==255) value[Alarm01]=0; else value[Alarm01]=EEPROM.read(AlarmArmedEEPROMAddress);
    if (EEPROM.read(LEDsLockEEPROMAddress)==255) LEDsLock=false; else LEDsLock=EEPROM.read(LEDsLockEEPROMAddress);
    Serial.print("led lock=");
    Serial.println(LEDsLock);
    
  pinMode(RedLedPin, OUTPUT);
  pinMode(GreenLedPin, OUTPUT);
  pinMode(BlueLedPin, OUTPUT);
    
  tone1.begin(pinBuzzer);
  song=parseSong(song);
  
  pinMode(LEpin, OUTPUT);
  pinMode(DHVpin, OUTPUT);
  
 // SPI setup

  SPI.begin(); // 
  SPI.setDataMode (SPI_MODE3); // Mode 3 SPI
  SPI.setClockDivider(SPI_CLOCK_DIV128); // SCK = 16MHz/128= 125kHz
 
  //buttons pins inits
  pinMode(pinSet,  INPUT_PULLUP);
  pinMode(pinUp,  INPUT_PULLUP);
  pinMode(pinDown,  INPUT_PULLUP);
  ////////////////////////////
  pinMode(pinBuzzer, OUTPUT);
  
  //buttons objects inits
  setButton.debounceTime   = 20;   // Debounce timer in ms
  setButton.multiclickTime = 30;  // Time limit for multi clicks
  setButton.longClickTime  = 2000; // time until "held-down clicks" register
  
  upButton.debounceTime   = 20;   // Debounce timer in ms
  upButton.multiclickTime = 30;  // Time limit for multi clicks
  upButton.longClickTime  = 2000; // time until "held-down clicks" register

  downButton.debounceTime   = 20;   // Debounce timer in ms
  downButton.multiclickTime = 30;  // Time limit for multi clicks
  downButton.longClickTime  = 2000; // time until "held-down clicks" register
  
  //
  //digitalWrite(DHVpin, HIGH); // on MAX1771 Driver  Hight Voltage(DHV) 110-220V
  //!!!!!!!!!!!!!!!!!!!!!!!!!!!!!!!!!!!!!!!!!!!!!!!!
  doTest();
  //!!!!!!!!!!!!!!!!!!!!!!!!!!!!!!!!!!!!!!!!!!!!!!!
  if (LEDsLock==1)
    {
      setLEDsFromEEPROM();
    }
  getRTCTime();
  setTime(RTC_hours, RTC_minutes, RTC_seconds, RTC_day, RTC_month, RTC_year);
  digitalWrite(DHVpin, LOW); // off MAX1771 Driver  Hight Voltage(DHV) 110-220V
  setRTCDateTime(RTC_hours,RTC_minutes,RTC_seconds,RTC_day,RTC_month,RTC_year,1); //записываем только что считанное время в RTC чтобы запустить новую микросхему
  digitalWrite(DHVpin, HIGH); // on MAX1771 Driver  Hight Voltage(DHV) 110-220V
  //p=song;
}

void rotateLeft(uint8_t &bits)
{
   uint8_t high_bit = bits & (1 << 7) ? 1 : 0;
  bits = (bits << 1) | high_bit;
}

int rotator=0; //index in array with RGB "rules" (increse by one on each 255 cycles)
int cycle=0; //cycles counter
int RedLight=255;
int GreenLight=0;
int BlueLight=0;
unsigned long prevTime=0; // time of lase tube was lit
unsigned long prevTime4FireWorks=0;  //time of last RGB changed
//int minuteL=0; //младшая цифра минут

/***************************************************************************************************************
MAIN Programm
***************************************************************************************************************/
void loop() {
  
  /* p=playmusic(p); */
  
  if ((millis()-prevTime4FireWorks)>5)
  {
    /* rotateFireWorks(); //change color (by 1 step) */
    prevTime4FireWorks=millis();
  }
    
  doIndication();
  
  setButton.Update();
  upButton.Update();
  downButton.Update();
  if (editMode==false) 
    {
      blinkMask=B00000000;
      
    } else if ((millis()-enteringEditModeTime)>60000) 
    {
      editMode=false;
      menuPosition=firstChild[menuPosition];
      blinkMask=blinkPattern[menuPosition];
    }
  if (setButton.clicks>0) //short click
    {
      p=0; //shut off music )))
      tone1.play(1000,100);
      enteringEditModeTime=millis();
      menuPosition=menuPosition+1;
      if (menuPosition==hModeIndex+1) menuPosition=TimeIndex;
      Serial.print(F("menuPosition="));
      Serial.println(menuPosition);
      Serial.print(F("value="));
      Serial.println(value[menuPosition]);
      
      blinkMask=blinkPattern[menuPosition];
      if ((parent[menuPosition-1]!=0) and (lastChild[parent[menuPosition-1]-1]==(menuPosition-1))) 
      {
        if ((parent[menuPosition-1]-1==1) && (!isValidDate())) 
          {
            menuPosition=DateDayIndex;
            return;
          }
        editMode=false;
        menuPosition=parent[menuPosition-1]-1;
        if (menuPosition==TimeIndex) setTime(value[TimeHoursIndex], value[TimeMintuesIndex], value[TimeSecondsIndex], day(), month(), year());
        if (menuPosition==DateIndex) setTime(hour(), minute(), second(),value[DateDayIndex], value[DateMonthIndex], 2000+value[DateYearIndex]);
        if (menuPosition==AlarmIndex) {EEPROM.write(AlarmTimeEEPROMAddress,value[AlarmHourIndex]); EEPROM.write(AlarmTimeEEPROMAddress+1,value[AlarmMinuteIndex]); EEPROM.write(AlarmTimeEEPROMAddress+2,value[AlarmSecondIndex]); EEPROM.write(AlarmArmedEEPROMAddress, value[Alarm01]);};
        if (menuPosition==hModeIndex) EEPROM.write(HourFormatEEPROMAddress, value[hModeValueIndex]);
        digitalWrite(DHVpin, LOW); // off MAX1771 Driver  Hight Voltage(DHV) 110-220V
        setRTCDateTime(hour(),minute(),second(),day(),month(),year()%1000,1);
        digitalWrite(DHVpin, HIGH); // on MAX1771 Driver  Hight Voltage(DHV) 110-220V
      }
      value[menuPosition]=extractDigits(blinkMask);
    }
  if (setButton.clicks<0) //long click
    {
      tone1.play(1000,100);
      if (!editMode) 
      {
        enteringEditModeTime=millis();
        if (menuPosition==TimeIndex) stringToDisplay=PreZero(hour())+PreZero(minute())+PreZero(second()); //temporary enabled 24 hour format while settings
      }
      menuPosition=firstChild[menuPosition];
      if (menuPosition==AlarmHourIndex) {value[Alarm01]=1; /*digitalWrite(pinUpperDots, HIGH);*/dotPattern=B10000000;}
      editMode=!editMode;
      blinkMask=blinkPattern[menuPosition];
      value[menuPosition]=extractDigits(blinkMask);
    }
   
  if (upButton.clicks != 0) functionUpButton = upButton.clicks;  
   
  if (upButton.clicks>0) 
    {
      p=0; //shut off music )))
      tone1.play(1000,100);
      incrementValue();
      if (!editMode) 
        {
          LEDsLock=false;
          EEPROM.write(LEDsLockEEPROMAddress, 0);
        }
    }
  
  if (functionUpButton == -1 && upButton.depressed == true)   
  {
   BlinkUp=false;
   if (editMode==true) 
   {
     if ( (millis() - upTime) > settingDelay)
    {
     upTime = millis();// + settingDelay;
      incrementValue();
    }
   }
  } else BlinkUp=true;
  
  if (downButton.clicks != 0) functionDownButton = downButton.clicks;
  
  if (downButton.clicks>0) 
    {
      p=0; //shut off music )))
      tone1.play(1000,100);
      dicrementValue();
      if (!editMode) 
      {
        LEDsLock=true;
        EEPROM.write(LEDsLockEEPROMAddress, 1);
        EEPROM.write(LEDsRedValueEEPROMAddress, RedLight);
        EEPROM.write(LEDsGreenValueEEPROMAddress, GreenLight);
        EEPROM.write(LEDsBlueValueEEPROMAddress, BlueLight);
      }
    }
  
  if (functionDownButton == -1 && downButton.depressed == true)   
  {
   BlinkDown=false;
   if (editMode==true) 
   {
     if ( (millis() - downTime) > settingDelay)
    {
     downTime = millis();// + settingDelay;
      dicrementValue();
    }
   }
  } else BlinkDown=true;
  
  if (!editMode)
  {
    if (upButton.clicks<0)
      {
        tone1.play(1000,100);
        RGBLedsOn=true;
        EEPROM.write(RGBLEDsEEPROMAddress,1);
        Serial.println("RGB=on");
        setLEDsFromEEPROM();
      }
    if (downButton.clicks<0)
    {
      tone1.play(1000,100);
      RGBLedsOn=false;
      EEPROM.write(RGBLEDsEEPROMAddress,0);
      Serial.println("RGB=off");
    }
  }
  
    
  static bool updateDateTime=false;
  switch (menuPosition)
  {
    case TimeIndex: //time mode
       stringToDisplay=updateDisplayString();
       doDotBlink();
       checkAlarmTime();
       break;
    case DateIndex: //date mode
      stringToDisplay=PreZero(day())+PreZero(month())+PreZero(year()%1000);
      dotPattern=B01000000;//turn on lower dots
      /*digitalWrite(pinUpperDots, LOW);
      digitalWrite(pinLowerDots, HIGH);*/
      checkAlarmTime();
      break;
    case AlarmIndex: //alarm mode
      stringToDisplay=PreZero(value[AlarmHourIndex])+PreZero(value[AlarmMinuteIndex])+PreZero(value[AlarmSecondIndex]);
     if (value[Alarm01]==1) /*digitalWrite(pinUpperDots, HIGH);*/ dotPattern=B10000000; //turn on upper dots
           else 
           {
             /*digitalWrite(pinUpperDots, LOW);
             digitalWrite(pinLowerDots, LOW);*/
             dotPattern=B00000000; //turn off upper dots
           }
      checkAlarmTime();
      break;
    case hModeIndex: //12/24 hours mode
      stringToDisplay="00"+String(value[hModeValueIndex])+"00";
      dotPattern=B00000000;//turn off all dots
      /*digitalWrite(pinUpperDots, LOW);
      digitalWrite(pinLowerDots, LOW);*/
      checkAlarmTime();
      break;
  }
}

String PreZero(int digit)
{
  if (digit<10) return String("0")+String(digit);
    else return String(digit);
}

void rotateFireWorks()
{
  if (!RGBLedsOn)
  {
    analogWrite(RedLedPin,0 );
    analogWrite(GreenLedPin,0);
    analogWrite(BlueLedPin,0); 
    return;
  }
  if (LEDsLock) return;
  RedLight=RedLight+fireforks[rotator*3];
  GreenLight=GreenLight+fireforks[rotator*3+1];
  BlueLight=BlueLight+fireforks[rotator*3+2];
  analogWrite(RedLedPin,RedLight );
  analogWrite(GreenLedPin,GreenLight);
  analogWrite(BlueLedPin,BlueLight);  
  cycle=cycle+1;
  if (cycle==255)
  {  
    rotator=rotator+1;
    cycle=0;
  }
  if (rotator>5) rotator=0;
}


void doIndication()
{
  
  static unsigned long lastTimeInterval1Started;
  if ((micros()-lastTimeInterval1Started)<fpsLimit) return;
  //if (menuPosition==TimeIndex) doDotBlink();
  lastTimeInterval1Started=micros();
    
  digitalWrite(LEpin, LOW);    // allow data input (Transparent mode)
   
  /* 
    SPI.transfer((b|dotPattern) & doEditBlink()); // anode
    SPI.transfer(highBytesArray[stringToDisplay.substring(curTube,curTube+1).toInt()]);
    SPI.transfer(lowBytesArray[stringToDisplay.substring(curTube,curTube+1).toInt()]);
  */
  //word SymbolArray2[10]={65534, 65023, 65279, 65407, 65471, 65503, 65519, 65527, 65531, 65533}; // used only for shiled with HW ver 1.0 //it has hardware bug in wiring
  
  unsigned long long Var64=0;
  unsigned long long tmpVar64=0;
  
  long digits=stringToDisplay.toInt();
  
  Var64=~Var64;
  tmpVar64=~tmpVar64;
  
  Var64=Var64&((SymbolArray[digits%10]|doEditBlink(5))<<6);
  Var64=Var64<<48;
  digits=digits/10;
  
  tmpVar64=(SymbolArray[digits%10]|doEditBlink(4))<<6;
  Var64|=(tmpVar64<<38);
  digits=digits/10;

  tmpVar64=(SymbolArray[digits%10]|doEditBlink(3))<<6;
  Var64|=(tmpVar64<<28);
  digits=digits/10;
  
  tmpVar64=(SymbolArray[digits%10]|doEditBlink(2))<<6;
  Var64|=(tmpVar64<<18);
  digits=digits/10;
  
  tmpVar64=(SymbolArray[digits%10]|doEditBlink(1))<<6;
  Var64|=(tmpVar64<<8);
  digits=digits/10;
  
  tmpVar64=(SymbolArray[digits%10]|doEditBlink(0))<<6>>2;
  Var64|=tmpVar64;
  
  Var64=(Var64>>4);
    
  unsigned int iTmp=0;
  
  iTmp=Var64>>56;
  SPI.transfer(iTmp);
  iTmp=Var64>>48;
  SPI.transfer(iTmp);
  iTmp=Var64>>40;
  SPI.transfer(iTmp);
  iTmp=Var64>>32;
  SPI.transfer(iTmp);
  iTmp=Var64>>24;
  SPI.transfer(iTmp);
  iTmp=Var64>>16;
  SPI.transfer(iTmp);
  iTmp=Var64>>8;
  SPI.transfer(iTmp);
  iTmp=Var64;
  SPI.transfer(iTmp);

  digitalWrite(LEpin, HIGH);    // allow data input (Transparent mode)    
  digitalWrite(LEpin, LOW);     // latching data 
}
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

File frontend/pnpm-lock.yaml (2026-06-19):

lockfileVersion: '9.0'

settings:
  autoInstallPeers: true
  excludeLinksFromLockfile: false

importers:

  .:
    dependencies:
      '@radix-ui/react-label':
        specifier: ^2.1.10
        version: 2.1.10(@types/react-dom@18.3.7(@types/react@18.3.29))(@types/react@18.3.29)(react-dom@18.3.1(react@18.3.1))(react@18.3.1)
      '@radix-ui/react-slot':
        specifier: ^1.3.0
        version: 1.3.0(@types/react@18.3.29)(react@18.3.1)
      '@radix-ui/react-switch':
        specifier: ^1.3.1
        version: 1.3.1(@types/react-dom@18.3.7(@types/react@18.3.29))(@types/react@18.3.29)(react-dom@18.3.1(react@18.3.1))(react@18.3.1)
      '@radix-ui/react-tabs':
        specifier: ^1.1.15
        version: 1.1.15(@types/react-dom@18.3.7(@types/react@18.3.29))(@types/react@18.3.29)(react-dom@18.3.1(react@18.3.1))(react@18.3.1)
      class-variance-authority:
        specifier: ^0.7.1
        version: 0.7.1
      clsx:
        specifier: ^2.1.1
        version: 2.1.1
      lucide-react:
        specifier: ^0.469.0
        version: 0.469.0(react@18.3.1)
      react:
        specifier: ^18.3.1
        version: 18.3.1
      react-dom:
        specifier: ^18.3.1
        version: 18.3.1(react@18.3.1)
      sonner:
        specifier: ^1.7.4
        version: 1.7.4(react-dom@18.3.1(react@18.3.1))(react@18.3.1)
      tailwind-merge:
        specifier: ^2.6.0
        version: 2.6.1
      tailwindcss-animate:
        specifier: ^1.0.7
        version: 1.0.7(tailwindcss@3.4.19)
    devDependencies:
      '@types/node':
        specifier: ^22.10.5
        version: 22.19.19
      '@types/react':
        specifier: ^18.3.18
        version: 18.3.29
      '@types/react-dom':
        specifier: ^18.3.5
        version: 18.3.7(@types/react@18.3.29)
      '@vitejs/plugin-react':
        specifier: ^4.3.4
        version: 4.7.0(vite@6.4.2(@types/node@22.19.19)(jiti@1.21.7))
      autoprefixer:
        specifier: ^10.4.20
        version: 10.5.0(postcss@8.5.15)
      postcss:
        specifier: ^8.4.49
        version: 8.5.15
      tailwindcss:
        specifier: ^3.4.17
        version: 3.4.19
      typescript:
        specifier: ^5.7.2
        version: 5.9.3
      vite:
        specifier: ^6.0.7
        version: 6.4.2(@types/node@22.19.19)(jiti@1.21.7)

packages:

  '@alloc/quick-lru@5.2.0':
    resolution: {integrity: sha512-UrcABB+4bUrFABwbluTIBErXwvbsU/V7TZWfmbgJfbkwiBuziS9gxdODUyuiecfdGQ85jglMW6juS3+z5TsKLw==}
    engines: {node: '>=10'}

  '@babel/code-frame@7.29.0':
    resolution: {integrity: sha512-9NhCeYjq9+3uxgdtp20LSiJXJvN0FeCtNGpJxuMFZ1Kv3cWUNb6DOhJwUvcVCzKGR66cw4njwM6hrJLqgOwbcw==}
    engines: {node: '>=6.9.0'}

  '@babel/compat-data@7.29.3':
    resolution: {integrity: sha512-LIVqM46zQWZhj17qA8wb4nW/ixr2y1Nw+r1etiAWgRM6U1IqP+LNhL1yg440jYZR72jCWcWbLWzIosH+uP1fqg==}
    engines: {node: '>=6.9.0'}

  '@babel/core@7.29.0':
    resolution: {integrity: sha512-CGOfOJqWjg2qW/Mb6zNsDm+u5vFQ8DxXfbM09z69p5Z6+mE1ikP2jUXw+j42Pf1XTYED2Rni5f95npYeuwMDQA==}
    engines: {node: '>=6.9.0'}

  '@babel/generator@7.29.1':
    resolution: {integrity: sha512-qsaF+9Qcm2Qv8SRIMMscAvG4O3lJ0F1GuMo5HR/Bp02LopNgnZBC/EkbevHFeGs4ls/oPz9v+Bsmzbkbe+0dUw==}
    engines: {node: '>=6.9.0'}

  '@babel/helper-compilation-targets@7.28.6':
    resolution: {integrity: sha512-JYtls3hqi15fcx5GaSNL7SCTJ2MNmjrkHXg4FSpOA/grxK8KwyZ5bubHsCq8FXCkua6xhuaaBit+3b7+VZRfcA==}
    engines: {node: '>=6.9.0'}

  '@babel/helper-globals@7.28.0':
    resolution: {integrity: sha512-+W6cISkXFa1jXsDEdYA8HeevQT/FULhxzR99pxphltZcVaugps53THCeiWA8SguxxpSp3gKPiuYfSWopkLQ4hw==}
    engines: {node: '>=6.9.0'}

  '@babel/helper-module-imports@7.28.6':
    resolution: {integrity: sha512-l5XkZK7r7wa9LucGw9LwZyyCUscb4x37JWTPz7swwFE/0FMQAGpiWUZn8u9DzkSBWEcK25jmvubfpw2dnAMdbw==}
    engines: {node: '>=6.9.0'}

  '@babel/helper-module-transforms@7.28.6':
    resolution: {integrity: sha512-67oXFAYr2cDLDVGLXTEABjdBJZ6drElUSI7WKp70NrpyISso3plG9SAGEF6y7zbha/wOzUByWWTJvEDVNIUGcA==}
    engines: {node: '>=6.9.0'}
    peerDependencies:
      '@babel/core': ^7.0.0

  '@babel/helper-plugin-utils@7.28.6':
    resolution: {integrity: sha512-S9gzZ/bz83GRysI7gAD4wPT/AI3uCnY+9xn+Mx/KPs2JwHJIz1W8PZkg2cqyt3RNOBM8ejcXhV6y8Og7ly/Dug==}
    engines: {node: '>=6.9.0'}

  '@babel/helper-string-parser@7.27.1':
    resolution: {integrity: sha512-qMlSxKbpRlAridDExk92nSobyDdpPijUq2DW6oDnUqd0iOGxmQjyqhMIihI9+zv4LPyZdRje2cavWPbCbWm3eA==}
    engines: {node: '>=6.9.0'}

  '@babel/helper-validator-identifier@7.28.5':
    resolution: {integrity: sha512-qSs4ifwzKJSV39ucNjsvc6WVHs6b7S03sOh2OcHF9UHfVPqWWALUsNUVzhSBiItjRZoLHx7nIarVjqKVusUZ1Q==}
    engines: {node: '>=6.9.0'}

  '@babel/helper-validator-option@7.27.1':
    resolution: {integrity: sha512-YvjJow9FxbhFFKDSuFnVCe2WxXk1zWc22fFePVNEaWJEu8IrZVlda6N0uHwzZrUM1il7NC9Mlp4MaJYbYd9JSg==}
    engines: {node: '>=6.9.0'}
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

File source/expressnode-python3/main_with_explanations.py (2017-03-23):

import RPi.GPIO as GPIO
from collections import OrderedDict
from datetime import datetime
from datetime import timedelta
import time
import json
import re
import pyinotify #you are going to have to install this via Pip or from source
import os
import signal
import subprocess

GPIO.setmode(GPIO.BCM)
GPIO.setup(17, GPIO.OUT) #GPIO 17 EN 1, 2
GPIO.setup(5, GPIO.OUT) #GPIO 5 INPUT 1
GPIO.setup(6, GPIO.OUT) #GPIO 6 INPUT 2

currentlyModifying = False #Since the event based stuff will look at when a JSON file is written/closed, we want to be able to modify the JSON files within this Python Program without setting off the event handler. Hence, This will be modified so that we don't get a weird recurive structure that traps the program in an infinite loop
wm = pyinotify.WatchManager()  # Watch Manager
mask = pyinotify.IN_CLOSE_WRITE | pyinotify.IN_OPEN  # watched events
timeWatcher = wm.add_watch('webinterface/public/json/time.json', mask, rec=False) #This adds a watcher that watches the time.json file
alarm1Watcher = wm.add_watch('webinterface/public/json/alarm1.json', mask, rec=False) #This adds a watcher that watches the alarm1.json file
alarm2Watcher = wm.add_watch('webinterface/public/json/alarm2.json', mask, rec=False) #This adds a watcher that watches the alarm2.json file
alarm3Watcher = wm.add_watch('webinterface/public/json/alarm3.json', mask, rec=False) #This adds a watcher that watches the alarm3.json file
alarm4Watcher = wm.add_watch('webinterface/public/json/alarm4.json', mask, rec=False) #This adds a watcher that watches the alarm4.json file
snoozeWatcher = wm.add_watch('webinterface/public/json/snooze.json', mask, rec=False) #This adds a watcher that watches the snooze.json file

class Alarm:
    def __init__(self, arg): #where arg is the name of a configuration file
        with open(arg) as data_file:
            data = json.load(data_file)
        self.name = data["name"] #Since the json.load will construct a dictionary, we can use the dictionary key to get the dictionary value
        self.time = data["time"] #Since the json.load will construct a dictionary, we can use the dictionary key to get the dictionary value
        self.sound = data["sound"] #Since the json.load will construct a dictionary, we can use the dictionary key to get the dictionary value
        self.vibration = data["vibration"] #Since the json.load will construct a dictionary, we can use the dictionary key to get the dictionary value
        self.currentStatus = "off" #When initialized, we don't want the alarm to be on
    def updateAlarm(self, arg): #identical to the class contructor __init__, but the constructor can only be called when the class is initialized
        with open(arg) as data_file:
            data = json.load(data_file)
        self.name = data["name"] #Since the json.load will construct a dictionary, we can use the dictionary key to get the dictionary value
        self.time = data["time"] #Since the json.load will construct a dictionary, we can use the dictionary key to get the dictionary value
        self.sound = data["sound"] #Since the json.load will construct a dictionary, we can use the dictionary key to get the dictionary value
        self.vibration = data["vibration"] #Since the json.load will construct a dictionary, we can use the dictionary key to get the dictionary value

def readTime(arg): #specifically to get time from the Node updated file time.json
    with open(arg) as data_file:
        data = json.load(data_file)
    return(data["time"])

def readBool(arg): #specifically to get the snooze file from the snooze.json file
    with open(arg) as data_file:
        data = json.load(data_file)
    return(data['snooze'])
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

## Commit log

2016-10-18 fixed pialarm directory structure
    [Adafruit_I2C.py, ads1x15_ex_comparator.py, pialarm.py]
2016-11-18 mv sound samples
2016-11-24 added schematics (Fritzing Program Format)
    [PiAlarm.fzz]
2016-11-26 Added Schematic Under assets/AtomicClockSchematic.fzz
    [AtomicClockSchematic.fzz]
2016-11-26 moved hberg32's PiAlarm.fzz schematic file to hberg32/
    [PiAlarm.fzz]
2016-11-26 moved away from Bootstrap Toggle to Switchdashery
2016-12-05 more changes to web interface
    -ability to change alarm sound
    -Snooze Button
2017-03-22 fixed schematic
    [AtomicClockSchematic.fzz]
2017-03-24 switch Fonts
    Apple San Francisco (Limited License. Subject to the terms of this License, you may use the Apple Font solely for creating mock-ups of user interfaces to be used in software products running on Apple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
    Umbra (not copyright permissive, hence, I have no right to distribute) to OstrichSans (SIL Open Font License)
2017-06-11 golang mod
    fixing golang code
    [AtomicClockSchematic.fzz]
2017-11-15 Prometheus 1.1.0 Complete!
    -Fixed jQuery ajax caching. (Forces web page to reload the JSON file from the server every time. Key to getting the most updated alarm information)
    -Broke apart the Prometheus Golang program into easier to understand packages
    -Updated Documentation
    -Removed reliance on relative paths, and explicitly call function to find location of the server executable to find the public file (important for when Prometheus is started through a daemon process such as rc.local)
    [main.py, main_with_explanations.py]
2017-11-24 added soldering stuff
2017-11-24 added print statements to debug code
2017-11-26 added single quotes to awk 'NR==1{print }' in utils function GetIP
2017-11-27 Finished 2.0.0-beta
    -Finished fixing utils.OverTenMinutes()
    -Improved comments for godoc
    -Fixed issues with auto-restart network on restart command crashing prometheus
    -Added ability to disable email notifications when Prometheus detects a change in IP (for people that use DDNS)
    -Added ability to change recipient email from front-end
    -Added information for track information on the front-end
2017-11-30 Moved all files to be more go friendly
    [PiAlarm.fzz]
2018-01-03 2.2.0 complete
    -Finished splitting front-end into Home/Settings/About sections for Clarity (Using mainly vue.js conditional rendering for Home and About, but standard JavaScript (html tag display property modification for Settings [because v-if/v-else-if messes up the non-Vue.js JavaScript binding to elements because using v-if prevents elements from rendering initially. Hence, for settings, I render the elements, then hide it via display="none", then set display="" when I "Settings" is clicked.
    -Added basic About page which shows a graphic about how to use the Clock's Front End in depth.
    -Finished the LED color setting functionality (With HTML Color Wheel)
    -Added some more shout outs in the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
2018-01-08 Added modified NCS314 Nixie Sketch
    -Custom NCS314 nixie sketch which reads time and desired LED color from serial USB.
    -Special thanks to Afch for all his help.
2018-01-18 modified arduino sketch for clock
2018-01-24 removed testing sequence from NCS314HW1.1.ino file
    removed initialization sequence (presumably there to reliably test the clocks before shipping out of the factory which nonetheless added about 5 seconds to the initialization sequence).
    By doing this, I was able to fix the problem that the clock was starting faster than my main program, and crashing it
    [NixieClockShieldNCS314HW1.1.ino]
2026-04-30 Add demo build mode for cloud-hosted UI showcase
    Compile-time switch via `-tags demo` that bypasses GPIO, USB-serial
    Nixie output, and cvlc playback. Alarm triggers broadcast WebSocket
    events instead, and the Vue frontend renders toast popups to emulate
    hardware activity.
